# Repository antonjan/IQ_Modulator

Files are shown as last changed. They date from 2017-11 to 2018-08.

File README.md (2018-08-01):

# IQ_Modulator for Cubesat Transmitter.
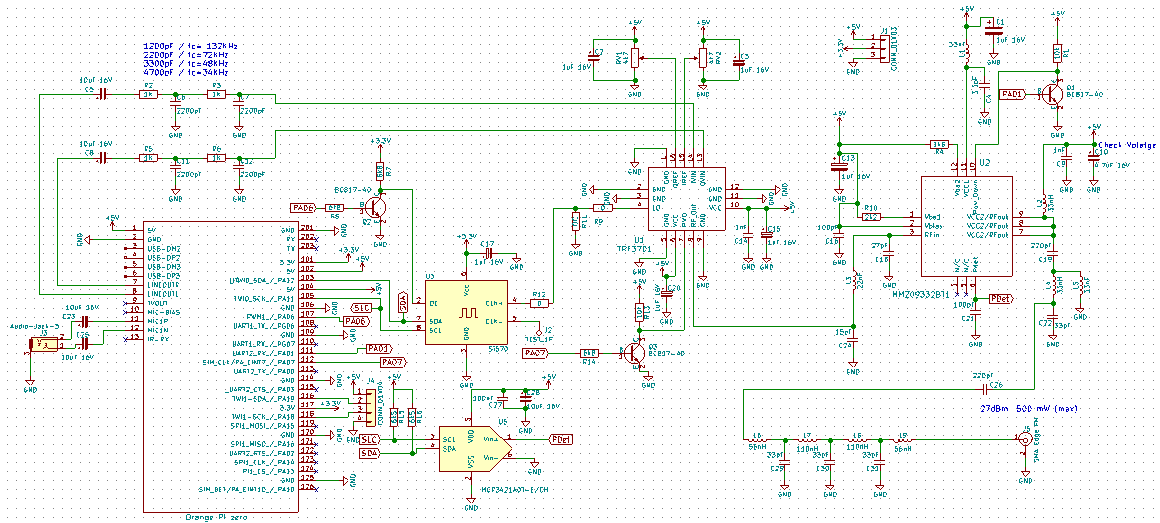
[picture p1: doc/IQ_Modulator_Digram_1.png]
<br>
IQ Modulator for 2M generating IQ stream via Audio PCM codec as modelation and using I2C to controle the RF local oselator for the RF mixer. The modulated RF signal is the Amplified to about +27dbm. (estimated 500mW)<br>
I2C Control for LO Local Osxelator with IQ moualtor RF amp and SAW and Ceremic output filters to antenna.<br>
<b><This is not complete yet still designing ></b>
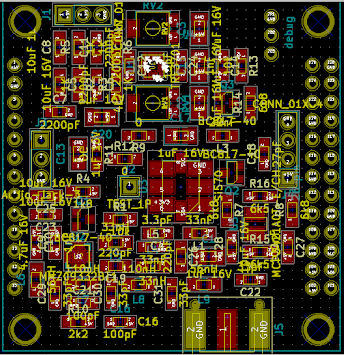
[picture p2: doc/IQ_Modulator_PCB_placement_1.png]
<br>
3d View<br>
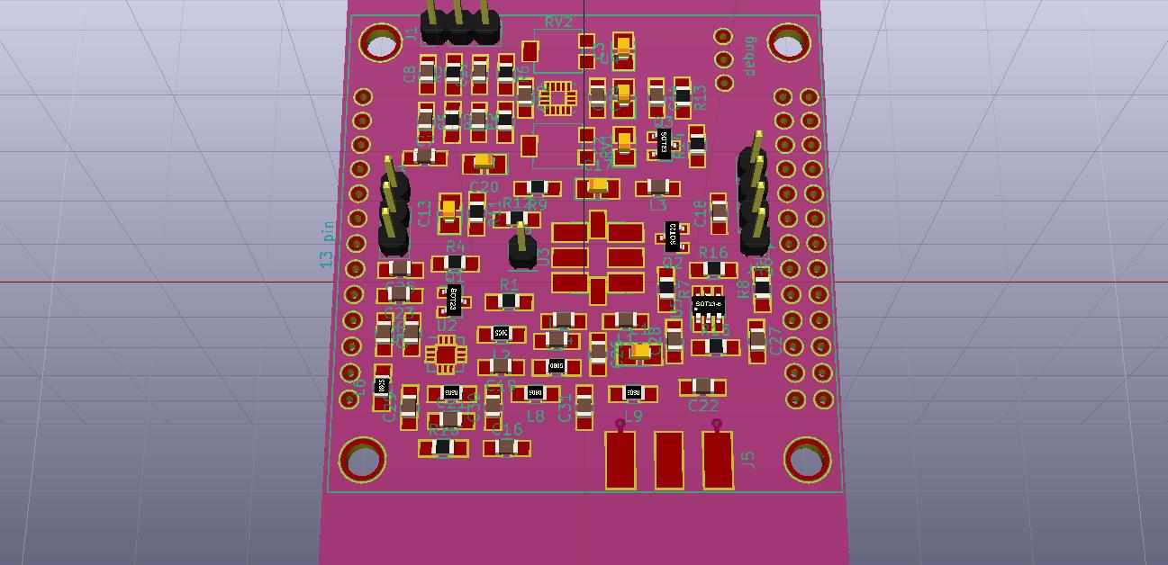
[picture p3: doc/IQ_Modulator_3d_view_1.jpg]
<br>
#Component list
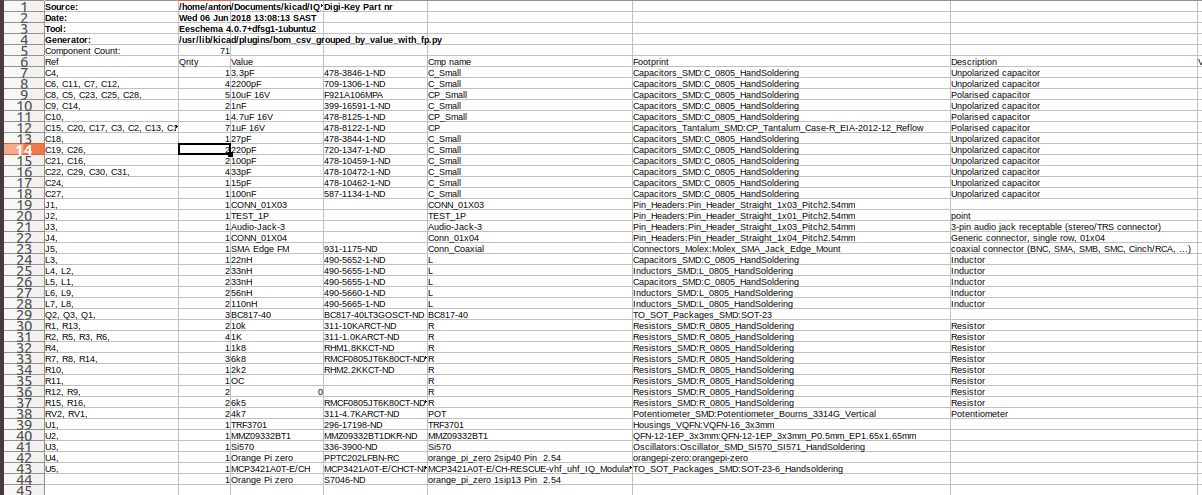
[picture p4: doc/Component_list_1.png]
<br>  
# OBC and SDR  
I am considering using Orange Pi rather than Raspberry as it has build in Audio in and out with a smaller footprint<br>
An another advantage of the Orange Pi is the additional USB ports witch I want to enable for the RTL dongle to be used as receiver.<br>
The software concept was tested using gnuradio for transponder with a hackrf for TX and a rtl sdr dongle for RX.<br>
I am still working on the telemetry witch works on its own but I need to combine it with Gnuraio transponder.<br>
I have to telemetry modes at the moment CW send Calsign and cubesat name and settings. APRS 1200 FSK sending the status of transponder<br>
# Power
Total power usage of board still needs to be calculated but my estimation with full power is 2w including Orange pi.<br>
Power usage in sleep mode possibly 500mw<br>
The PCB design was done in Kicad<br>
<br>
# Project Status.
This project is not compleet yet. (Almost done 12/06/2018)  
My plan is to have it working by 15 July 2018.
The board V3 has the wrong pin configuration for U2 trf3701
I am now working on V4 ans need to get it working by 9 August 2018 for the BACAR6 baloon project.
# Todo
1) Real time clock (done) I had to remove the Real time clock as there is not enuf space on the PCB<br>
2) I2C pull up resistors (done)<br>
3) Maybe different 70cm filter. (2m filter was changed to discrete components pi 5 stage 40db down. The 70cm filter was removed as there was now space on the PCB)<br>
4) CS for ic's<br>
5) Temprature and Tx power measurementA/D. (The A/D was added using MCP3421A0T-E/CH and will read the power output of the MMZ09332BT1 30db power amp that should give us about +27dbm. This A/D reading can then be used to adjust the ALC level in the IQ stream)<br>
6) Battery and solar Voltage Monitoring (A/D) (I had to remove this as there was no space on the PCB Board)<br>
7) I forgot to add a 4k7 resistor to base of Q1. Fixed and is now added.
8) Board placement redone thats why I have vertion 3 as I could not root all routes.  
# Constranes 
1) Small Board to fit all components.
2) My Pick and Place machien can not place components smaller that 0805.  
# Software
The software for this Board will be in the following repository
https://github.com/antonjan/Balloon-Transponder

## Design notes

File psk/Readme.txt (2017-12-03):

Deails here http://www.radiotecnia.es/raspberry-pi-based-psk31-transmitter/

The service must be run with root permissions. Help is shown with this command:

pi@raspberrypi ~/psk31 $ ./psk31 --help
Options:
 --amplitude=<n> Signal amplitude (0 .. 1]
 --clock-div=<n> Fractional divisor for carrier [4096 .. 16773120]
 Note: frequency = 500 MHz / (clock-div / 4096)
 --frequency=<f> Carrier frequency, in MHz [0.125 .. 500]
 Note: this is overridden by clock-div
 --help Show this help
 --mash=<n> Set number of MASH stages [0 .. 3]
 --pcm Use PCM clock instead of PWM clock for signal generation
 --rc=<f> Set signal filter RC value (s)
 --timeout=<n> Number of zeros before switching off. 0 for infinite.

Amplitude should be the highest. “mash” parameter should be set to ‘1’. A ‘0’ value disables fractional pll values above 25 MHz. “rc” time constant should be that of the filter we have built. If we run the program with these parameters, an unmodulated carrier is sent:

    sudo ./psk31 --mash=1 --rc=0.0047 --timeout=20 --frequency=7.042

No root permissions are needed for sending text. We can dump the content on the transmission buffer through /dev/psk31.data device as shown:

    echo "CQ CQ" > /dev/psk31.data

    cat fichero.txt > /dev/psk31.data

In this way:

    cat > /dev/psk31.data

we enter an interactive mode. We can write in the console and <Enter> sends the line to the buffer.

We can run this command to know the state of the service:

    nc -U /dev/psk31.stat

Which returns:

    amplitude 0.900000
    rc 0.004700
    clock_div 290826
    clock_mash 1
    clock_freq 7.042011
    timeout 20
    pending_char 53

To stop the service:

    sudo killall psk31

The actual divider value is not the “clock_div” number. The pll has a 500 MHz reference which is divided by a number with integer and fractional parts each represented with 12 bits. That is to say, it can divide fractions 2^12 or 4096 times smaller than one. In this case, 290826 means 500 is divided by 71 + 10/4096 (as 71·4096=290816). We have launched the service for 7.042 MHz which is obtained as 500 · 4096 / 290826 = 7.042.

This also means the resolution (the frequency step) is not fixed, but dependent on the starting frequency. Being ‘N’ an integer number between 2^13 and 2^23 that is 8.192 and 8.388.608, by means of this equation:

F = 500e6/(N/4096) [Hz]

we get frequencies between 244 kHz and 250 MHz. The rest of dividing N by 4096 (2¹²) is the fractional part.

The resolution is:

f1-f2 = 500e6/(N/4096) – 500e6/((N+1)/4096))

After some algebra:

f1 – f2 = f1² / (500e6*4096) [Hz]

Which means the resolution step is proportional to the square of the frequency.

For example, in 145 MHz  10 kHz.
In 50 MHz the step is 1,2 kHz.
In 28 MHz the step is 382 Hz.
In 7 MHz the step is 24 Hz.

This video shows the first trials of the prototype, without amplification, transmitting a short text across the room:

Conclusions and future prospects

My signal in 20 and 40 meters bands was heard 5 km away. This circuit can be improved regarding the schematic, pcb design and component election, but its goal was proving the feasibility of the idea. It is not supposed to be a convinient way to make QSOs because, among other things, a separate receiver and decoder would be needed. But it could be useful as an autonomous beacon for telemetry or propagation study. Moreover, the sigma-delta and the baseband coupling are tools which can be utilized in different projects.

The circuit could be improved in the following ways: pin 16 (gpio 23) is set at high level when the service is running. It could be used for biasing the base of 2N2222 transistor and prevent it from drawing current when unnecessary. The oscillator has a square waveshape and a dedicate filter for each band should be used. Likewise, SA602 differential output would be better coupled by means of a transformer in order to reduce distorsion and duplicate power. The same circuit can be used with the programs indicated above for transmitting other modulations, save for rpitx which makes use of pin 12 (gpio 18) for the PLL output instead of pin 7 (gpio 4); the connections should be made interchangeable.

By EA4GMZ • Electrónica y equipos, Otros •

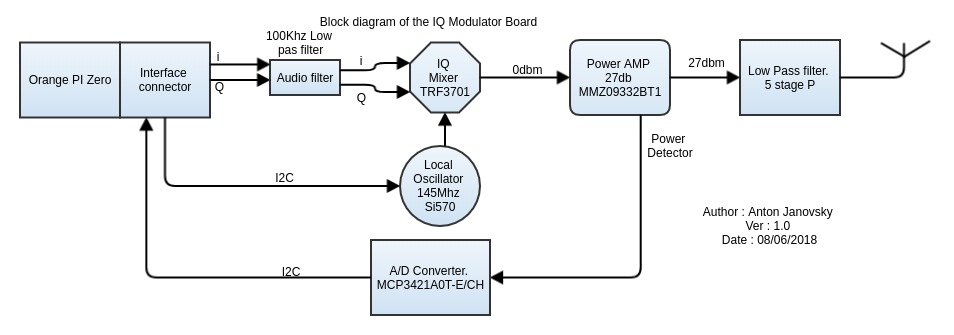
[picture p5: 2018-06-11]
doc/IQ_Modulator_Block_Diagram_v1.jpg

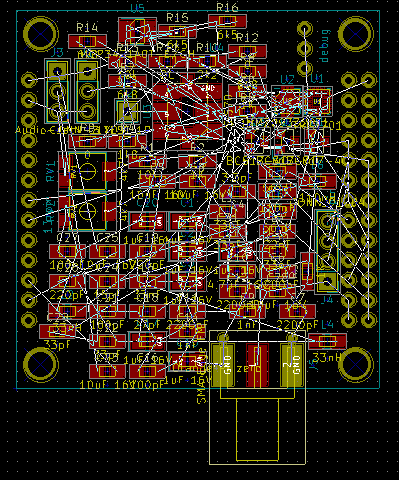
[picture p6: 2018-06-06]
doc/IQ_Modulator_PCB_1.png

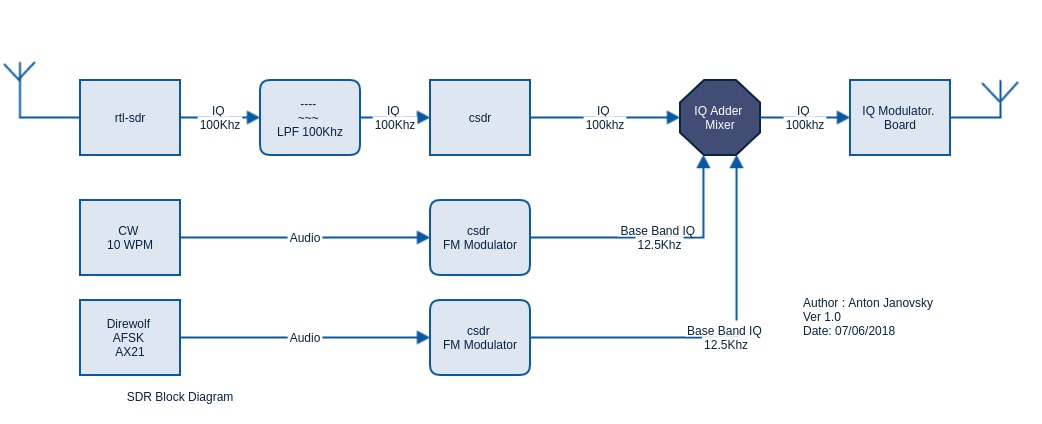
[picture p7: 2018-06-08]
doc/Block_Diagram_v1.jpg

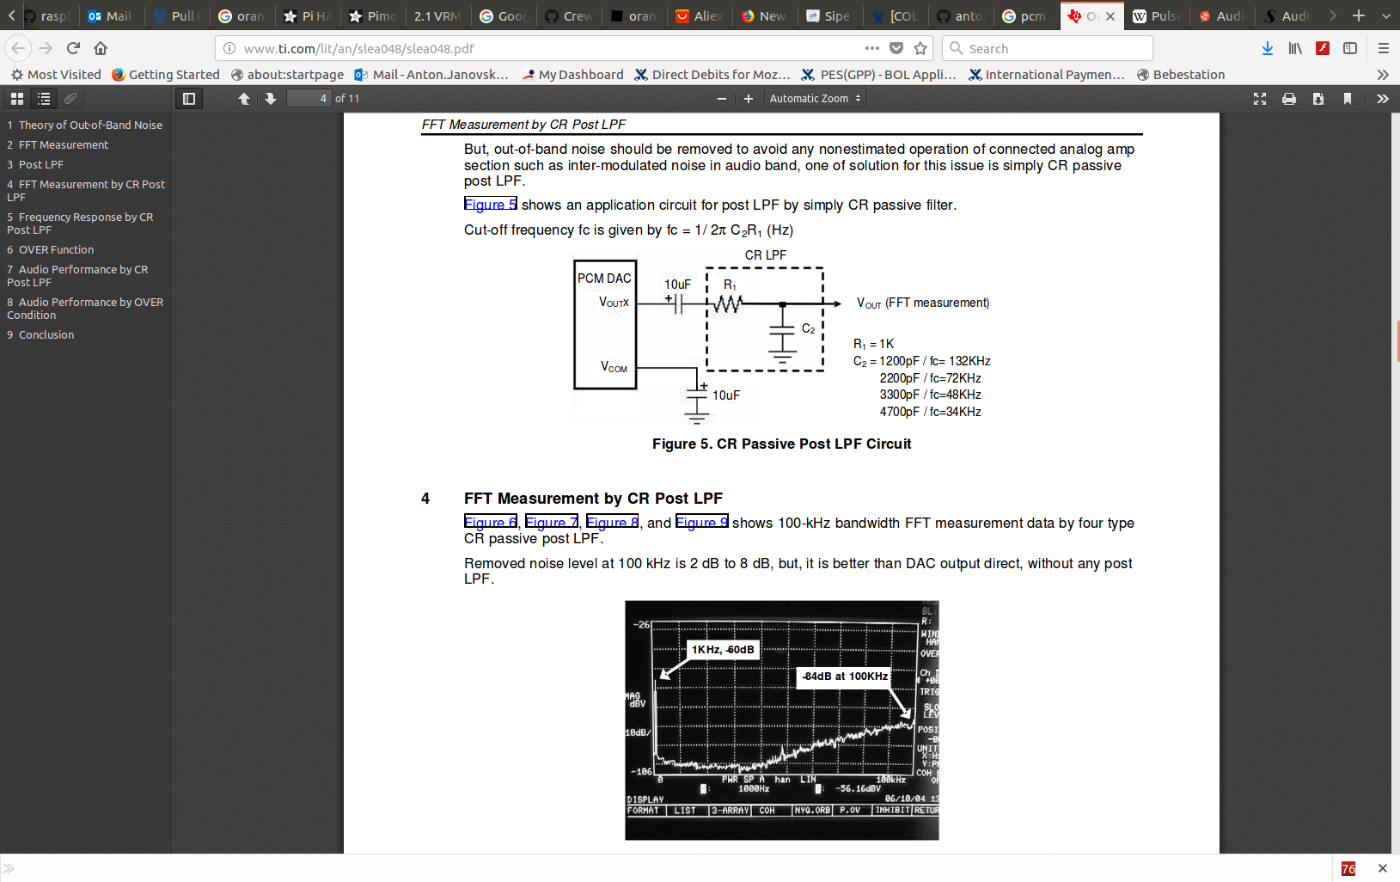
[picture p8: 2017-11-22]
Audio_output_Filter.png

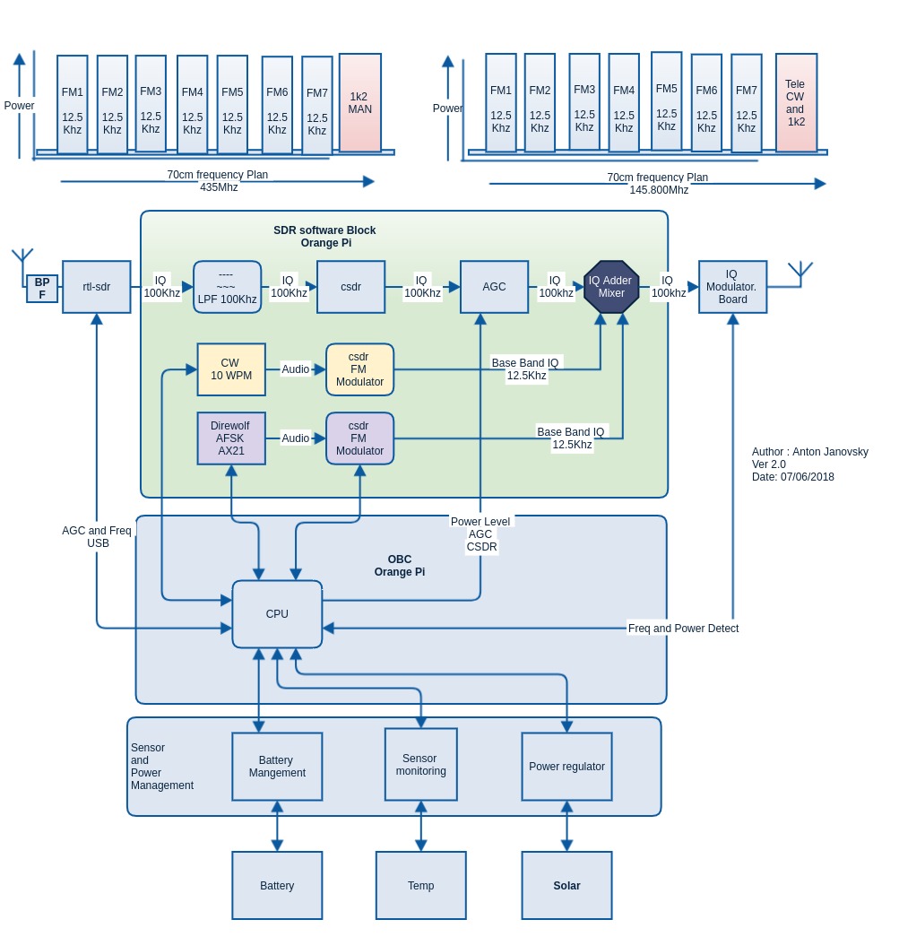
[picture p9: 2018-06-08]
doc/Block_Diagram_v2.jpg

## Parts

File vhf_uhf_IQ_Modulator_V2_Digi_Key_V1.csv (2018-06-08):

# | Quantity | Part Number | Manufacturer Part Number | Description | Customer Reference | Backorder | Unit Price | Extended Price
1 | 100 | 478-3846-1-ND | 08052U3R3DAT2A | CAP CER 3.3PF 200V C0G/NP0 0805 | 3.3PF | 0 | 180,540 | R 180,54
2 | 100 | 399-16591-1-ND | C0805C102J5HACAUTO | CAP CER 0805 1NF 50V ULTRA STABL | 1NF | 0 | 81,130 | R 81,13
3 | 100 | 478-8125-1-ND | F921A475MPA | CAP TANT 4.7UF 10V 20% 0805 | 4.7UF 16V | 0 | 185,550 | R 185,55
4 | 100 | 478-3844-1-ND | 08052U270JAT2A | CAP CER 27PF 200V C0G/NP0 0805 | 27PF | 0 | 166,270 | R 166,27
5 | 100 | 478-10472-1-ND | 08052U330JAT2A | CAP CER 33PF 200V NP0 0805 | 33PF | 0 | 188,930 | R 188,93
6 | 100 | 587-1134-1-ND | LMK212SD104KG-T | CAP CER 0.1UF 10V 0805 | 100NF | 0 | 210,840 | R 210,84
7 | 50 | 490-5652-1-ND | LQW2BAS22NJ00L | FIXED IND 22NH 500MA 220 MOHM | 22NH | 0 | 198,820 | R 99,41
8 | 50 | 490-5655-1-ND | LQW2BAS33NJ00L | FIXED IND 33NH 500MA 270 MOHM | 33NH | 0 | 265,400 | R 132,70
9 | 50 | 490-5660-1-ND | LQW2BAS56NJ00L | FIXED IND 56NH 500MA 340 MOHM | 56NH | 0 | 198,820 | R 99,41
10 | 50 | 490-5665-1-ND | LQW2BASR11J00L | FIXED IND 110NH 400MA 480 MOHM | 110NH | 0 | 198,820 | R 99,41
11 | 4 | 296-17198-ND | TRF3701IRHC | IC QUADRATURE MODULATOR 16-VQFN | TRF3701 | 0 | 20,896,000 | R 835,84
12 | 4 | MMZ09332BT1DKR-ND | MMZ09332BT1 | IC AMP HBT INGAP | MMZ09332BT1 | 0 | 12,992,000 | R 519,68
13 | 4 | 336-3900-ND | 570MAC000118DG | OSC XO 100KHZ-250MHZ LVPECL SMD | SI570 | 0 | 14,398,000 | R 575,92
14 | 4 | MCP3421A0T-E/CHCT-ND | MCP3421A0T-E/CH | IC ADC 18BIT 3.75SPS 1CH SOT23-6 | MCP3421A0T-E/CH | 0 | 3,080,000 | R 123,20
15 | 100 | 311-3619-1-ND | CC0805JRX7R9BB222 | CAP CER 2200PF 50V X7R 0805 | 2200PF | 0 | 40,560 | R 40,56
16 | 20 | 490-6104-1-ND | GR442QR73D221KW01L | CAP CER 220PF 2KV X7R 1808 | 220PF | 0 | 472,000 | R 94,40
17 | 100 | 1276-2585-1-ND | CL21C150JB61PNC | CAP CER 15PF 50V C0G/NP0 0805 | 15PF | 0 | 67,610 | R 67,61

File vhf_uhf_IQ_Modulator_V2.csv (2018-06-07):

Source: | /home/anton/Documents/kicad/IQ_Modulator/vhf_uhf_IQ_Modulator_V2.sch |  | Digi-Key Part nr
Date: | Wed 06 Jun 2018 13:08:13 SAST
Tool: | Eeschema 4.0.7+dfsg1-1ubuntu2
Generator: | /usr/lib/kicad/plugins/bom_csv_grouped_by_value_with_fp.py
Component Count: | 71
Ref | Qnty | Value |  | Cmp name | Footprint | Description | Vendor
C4, | 1 | 3.3pF | 478-3846-1-ND | C_Small | Capacitors_SMD:C_0805_HandSoldering | Unpolarized capacitor
C6, C11, C7, C12, | 4 | 2200pF | 709-1306-1-ND | C_Small | Capacitors_SMD:C_0805_HandSoldering | Unpolarized capacitor
C8, C5, C23, C25, C28, | 5 | 10uF 16V | 478-11412-1-ND | CP_Small | Capacitors_SMD:C_0805_HandSoldering | Polarised capacitor
C9, C14, | 2 | 1nF | 399-16591-1-ND | C_Small | Capacitors_SMD:C_0805_HandSoldering | Unpolarized capacitor
C10, | 1 | 4.7uF 16V | 478-8125-1-ND | CP_Small | Capacitors_SMD:C_0805_HandSoldering | Polarised capacitor
C15, C20, C17, C3, C2, C13, C1, | 7 | 1uF 16V | 478-8122-1-ND | CP | Capacitors_Tantalum_SMD:CP_Tantalum_Case-R_EIA-2012-12_Reflow | Polarised capacitor
C18, | 1 | 27pF | 478-3844-1-ND | C_Small | Capacitors_SMD:C_0805_HandSoldering | Unpolarized capacitor
C19, C26, | 2 | 220pF | 720-1347-1-ND | C_Small | Capacitors_SMD:C_0805_HandSoldering | Unpolarized capacitor
C21, C16, | 2 | 100pF | 478-10459-1-ND | C_Small | Capacitors_SMD:C_0805_HandSoldering | Unpolarized capacitor
C22, C29, C30, C31, | 4 | 33pF | 478-10472-1-ND | C_Small | Capacitors_SMD:C_0805_HandSoldering | Unpolarized capacitor
C24, | 1 | 15pF | 478-10462-1-ND | C_Small | Capacitors_SMD:C_0805_HandSoldering | Unpolarized capacitor
C27, | 1 | 100nF | 587-1134-1-ND | C_Small | Capacitors_SMD:C_0805_HandSoldering | Unpolarized capacitor
J1, | 1 | CONN_01X03 |  | CONN_01X03 | Pin_Headers:Pin_Header_Straight_1x03_Pitch2.54mm
J2, | 1 | TEST_1P |  | TEST_1P | Pin_Headers:Pin_Header_Straight_1x01_Pitch2.54mm | point
J3, | 1 | Audio-Jack-3 |  | Audio-Jack-3 | Pin_Headers:Pin_Header_Straight_1x03_Pitch2.54mm | 3-pin audio jack receptable (stereo/TRS connector)
J4, | 1 | CONN_01X04 |  | Conn_01x04 | Pin_Headers:Pin_Header_Straight_1x04_Pitch2.54mm | Generic connector, single row, 01x04
J5, | 1 | SMA Edge FM | 931-1175-ND | Conn_Coaxial | Connectors_Molex:Molex_SMA_Jack_Edge_Mount | coaxial connector (BNC, SMA, SMB, SMC, Cinch/RCA, ...)
L3, | 1 | 22nH | 490-5652-1-ND | L | Capacitors_SMD:C_0805_HandSoldering | Inductor
L4, L2, | 2 | 33nH | 490-5655-1-ND | L | Inductors_SMD:L_0805_HandSoldering | Inductor
L5, L1, | 2 | 33nH | 490-5655-1-ND | L | Capacitors_SMD:C_0805_HandSoldering | Inductor
L6, L9, | 2 | 56nH | 490-5660-1-ND | L | Inductors_SMD:L_0805_HandSoldering | Inductor
L7, L8, | 2 | 110nH | 490-5665-1-ND | L | Inductors_SMD:L_0805_HandSoldering | Inductor
Q2, Q3, Q1, | 3 | BC817-40 | BC817-40LT3GOSCT-ND | BC817-40 | TO_SOT_Packages_SMD:SOT-23
R1, R13, | 2 | 10k | 311-10KARCT-ND | R | Resistors_SMD:R_0805_HandSoldering | Resistor
R2, R5, R3, R6, | 4 | 1K | 311-1.0KARCT-ND | R | Resistors_SMD:R_0805_HandSoldering | Resistor
R4, | 1 | 1k8 | RHM1.8KKCT-ND | R | Resistors_SMD:R_0805_HandSoldering | Resistor
R7, R8, R14, | 3 | 6k8 | RMCF0805JT6K80CT-ND | R | Resistors_SMD:R_0805_HandSoldering | Resistor
R10, | 1 | 2k2 | RHM2.2KKCT-ND | R | Resistors_SMD:R_0805_HandSoldering | Resistor
R11, | 0 | OC |  | R | Resistors_SMD:R_0805_HandSoldering | Resistor
R12, R9, | 2 | 0 | 541-0.0ACT-ND | R | Resistors_SMD:R_0805_HandSoldering | Resistor
R15, R16, | 2 | 6k5 | RMCF0805JT6K80CT-ND | R | Resistors_SMD:R_0805_HandSoldering | Resistor
RV2, RV1, | 2 | 4k7 | 311-4.7KARCT-ND | POT | Potentiometer_SMD:Potentiometer_Bourns_3314G_Vertical | Potentiometer
U1, | 1 | TRF3701 | 296-17198-ND | TRF3701 | Housings_VQFN:VQFN-16_3x3mm
U2, | 1 | MMZ09332BT1 | MMZ09332BT1DKR-ND | MMZ09332BT1 | QFN-12-1EP_3x3mm:QFN-12-1EP_3x3mm_P0.5mm_EP1.65x1.65mm
U3, | 1 | Si570 | 336-3900-ND | Si570 | Oscillators:Oscillator_SMD_SI570_SI571_HandSoldering
U4, | 1 | Orange Pi zero | PPTC202LFBN-RC | orange_pi_zero 2sip40 Pin 2.54 | orangepi-zero:orangepi-zero
U5, | 1 | MCP3421A0T-E/CH | MCP3421A0T-E/CHCT-ND | MCP3421A0T-E/CH-RESCUE-vhf_uhf_IQ_Modulator | TO_SOT_Packages_SMD:SOT-23-6_Handsoldering
 | 1 | Orange Pi zero | S7046-ND | orange_pi_zero 1sip13 Pin 2.54

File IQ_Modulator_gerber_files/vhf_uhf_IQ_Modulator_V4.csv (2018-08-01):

Id | Designator | Package | Quantity | Designation | Supplier and ref
1 | C1,C2,C3,C13,C15,C17,C20 | CP_Tantalum_Case-R_EIA-2012-12_Reflow | 7 | 1uF 16V
2 | C4 | C_0805_HandSoldering | 1 | 3.3pF
3 | C5,C8,C23,C25,C28 | C_0805_HandSoldering | 5 | 10uF 16V
4 | C6,C7,C11,C12 | C_0805_HandSoldering | 4 | 2200pF
5 | C9,C14 | C_0805_HandSoldering | 2 | 1nF
6 | C10 | C_0805_HandSoldering | 1 | 4.7uF 16V
7 | C16,C21 | C_0805_HandSoldering | 2 | 100pF
8 | C18 | C_0805_HandSoldering | 1 | 27pF
9 | C19,C26 | C_0805_HandSoldering | 2 | 220pF
10 | C22,C29,C30,C31 | C_0805_HandSoldering | 4 | 33pF
11 | C24 | C_0805_HandSoldering | 1 | 15pF
12 | C27 | C_0805_HandSoldering | 1 | 100nF
13 | J1 | Pin_Header_Straight_1x03_Pitch2.54mm | 1 | CONN_01X03
14 | J2 | Pin_Header_Straight_1x01_Pitch2.54mm | 1 | TEST_1P
15 | J3 | Pin_Header_Straight_1x03_Pitch2.54mm | 1 | Audio-Jack-3
16 | J4 | Pin_Header_Straight_1x04_Pitch2.54mm | 1 | CONN_01X04
17 | J5 | Molex_SMA_Jack_Edge_Mount | 1 | SMA Edge FM
18 | L1,L5 | C_0805_HandSoldering | 2 | 33nF
19 | L2,L4 | L_0805_HandSoldering | 2 | 33nH
20 | L3 | C_0805_HandSoldering | 1 | 22nF
21 | L6,L9 | L_0805_HandSoldering | 2 | 56nH
22 | L7,L8 | L_0805_HandSoldering | 2 | 110nH
23 | Q1,Q2,Q3 | SOT-23 | 3 | BC817-40
24 | R1,R13 | R_0805_HandSoldering | 2 | 10k
25 | R2,R3,R5,R6 | R_0805_HandSoldering | 4 | 1K
26 | R4 | R_0805_HandSoldering | 1 | 1k8
27 | R7,R8,R14 | R_0805_HandSoldering | 3 | 6k8
28 | R9,R12 | R_0805_HandSoldering | 2 | 0
29 | R10 | R_0805_HandSoldering | 1 | 2k2
30 | R11 | R_0805_HandSoldering | 1 | OC
31 | R15,R16 | R_0805_HandSoldering | 2 | 6k5
32 | RV1,RV2 | Potentiometer_Bourns_3314G_Vertical | 2 | 4k7
33 | U2 | QFN-12-1EP_3x3mm_P0.5mm_EP1.65x1.65mm | 1 | MMZ09332BT1
34 | U3 | Oscillator_SMD_SI570_SI571_HandSoldering | 1 | Si570
35 | U4 | orangepi-zero | 1 | Orange Pi zero
36 | U5 | SOT-23-6_Handsoldering | 1 | MCP3421A0T-E/CH
37 | R17 | R_0805_HandSoldering | 1 | 4k7
38 | U1 | VQFN-16_3x3mm_trf3701_new | 1 | TRF3701

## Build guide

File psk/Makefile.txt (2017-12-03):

.PHONY: all
all: psk31 varicode
	@echo Done

psk31: psk31.c
	@echo '   CC   $^'
	@gcc -O6 -Wall -o $@ $^ -lm

varicode: varicode.c
	@echo '   CC   $^'
	@gcc -o $@ $^

.PHONY: clean
clean:
	@rm -f psk31 varicode

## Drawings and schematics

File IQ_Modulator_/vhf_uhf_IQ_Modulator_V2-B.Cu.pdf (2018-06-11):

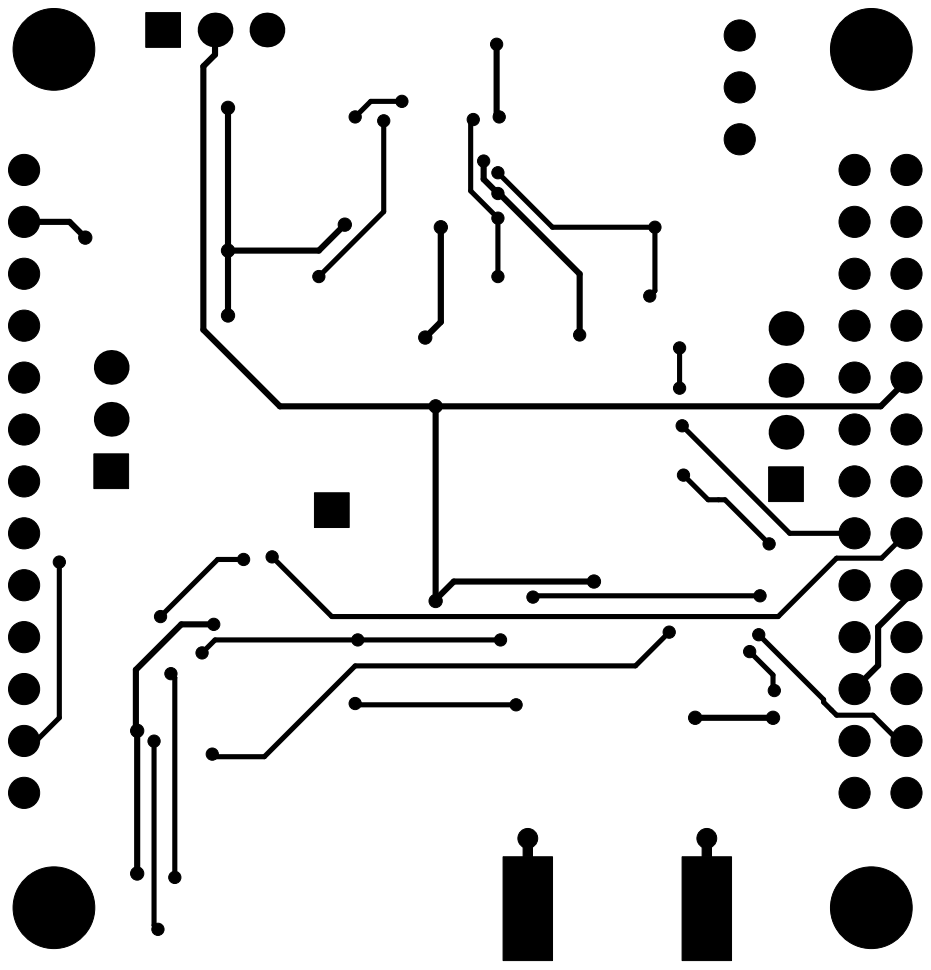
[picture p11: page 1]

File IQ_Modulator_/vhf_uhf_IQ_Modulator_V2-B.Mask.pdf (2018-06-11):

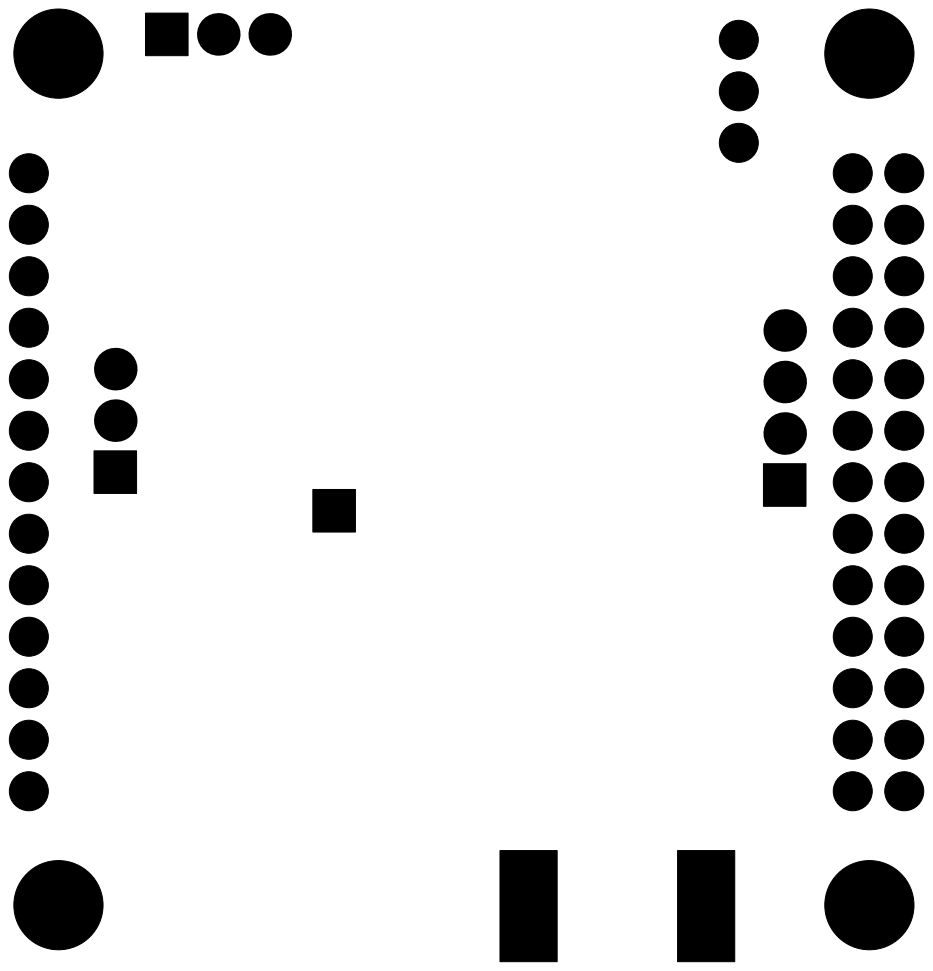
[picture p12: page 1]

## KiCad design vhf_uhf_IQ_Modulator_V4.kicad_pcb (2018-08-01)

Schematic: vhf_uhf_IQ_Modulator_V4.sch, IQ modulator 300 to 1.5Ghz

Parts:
C1, C2, C3, C13, C15, C17, C20: 1uF 16V; CP_Tantalum_Case-R_EIA-2012-12_Reflow
C4: 3.3pF; C_0805_HandSoldering
C5, C8, C23, C25, C28: 10uF 16V; C_0805_HandSoldering
C6, C7, C11, C12: 2200pF; C_0805_HandSoldering
C9, C14: 1nF; C_0805_HandSoldering
C10: 4.7uF 16V; C_0805_HandSoldering
C16, C21: 100pF; C_0805_HandSoldering
C18: 27pF; C_0805_HandSoldering
C19, C26: 220pF; C_0805_HandSoldering
C22, C29, C30, C31: 33pF; C_0805_HandSoldering
C24: 15pF; C_0805_HandSoldering
C27: 100nF; C_0805_HandSoldering
J1: CONN_01X03; Pin_Header_Straight_1x03_Pitch2.54mm
J2: TEST_1P; Pin_Header_Straight_1x01_Pitch2.54mm
J3: Audio-Jack-3; Pin_Header_Straight_1x03_Pitch2.54mm
J4: CONN_01X04; Pin_Header_Straight_1x04_Pitch2.54mm
J5: SMA Edge FM; Molex_SMA_Jack_Edge_Mount
L1, L5: 33nF; C_0805_HandSoldering
L2, L4: 33nH; L_0805_HandSoldering
L3: 22nF; C_0805_HandSoldering
L6, L9: 56nH; L_0805_HandSoldering
L7, L8: 110nH; L_0805_HandSoldering
Q1, Q2, Q3: BC817-40; SOT-23
R1, R13: 10k; R_0805_HandSoldering
R2, R3, R5, R6: 1K; R_0805_HandSoldering
R4: 1k8; R_0805_HandSoldering
R7, R8, R14: 6k8; R_0805_HandSoldering
R9, R12: 0; R_0805_HandSoldering
R10: 2k2; R_0805_HandSoldering
R11: OC; R_0805_HandSoldering
R15, R16: 6k5; R_0805_HandSoldering
R17: 4k7; R_0805_HandSoldering
RV1, RV2: 4k7; Potentiometer_Bourns_3314G_Vertical
U1: TRF3701; VQFN-16_3x3mm_trf3701_new
U2: MMZ09332BT1; QFN-12-1EP_3x3mm_P0.5mm_EP1.65x1.65mm
U3: Si570; Oscillator_SMD_SI570_SI571_HandSoldering
U4: Orange Pi zero; orangepi-zero
U5: MCP3421A0T-E/CH; SOT-23-6_Handsoldering

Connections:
+3V3: C17.1, J1.2, R7.2, U3.6, U4.101, U4.117
+5V: C1.1, C2.1, C3.1, C9.2, C10.1, C13.1, C14.2, C15.1, C16.2, C20.1, C27.2, C28.1, J1.1, J4.1, L1.1, L2.1, R1.2, R4.2, R10.2, R13.1, R15.1, R16.1, RV1.1, RV2.1, U1.6, U1.10, U2.2, U4.1, U4.102, U4.104, U5.5
GND: C1.2, C2.2, C3.2, C4.1, C6.2, C7.2, C9.1, C10.2, C11.2, C12.2, C13.2, C14.1, C15.2, C16.1, C17.2, C18.1, C20.2, C21.1, C22.1, C24.1, C27.1, C28.2, C29.1, C30.1, C31.1, J1.3, J3.3, J4.4, J5.2, L5.2, Q1.2 (E), Q2.2 (E), Q3.2 (E), R11.1, RV1.3, RV2.3, U1.1, U1.2, U1.3, U1.5, U1.9, U1.11, U1.12, U1.17, U2.13, U3.3, U4.2, U4.106, U4.109, U4.114, U4.120, U4.125, U4.201, U5.2, U5.6
unnamed: C4.2, L1.2, U2.11
unnamed: C5.1, U4.8
unnamed: C5.2, R2.2
unnamed: C6.1, R2.1, R3.2
unnamed: C7.1, R3.1, U1.14
unnamed: C8.1, U4.7
unnamed: C8.2, R5.2
unnamed: C11.1, R5.1, R6.2
unnamed: C12.1, R6.1, U1.13
unnamed: C18.2, L3.1, U2.3
unnamed: C19.1, L4.1, L5.1
unnamed: C19.2, L2.2, U2.7, U2.8, U2.9
unnamed: C22.2, C26.2, L4.2
unnamed: C23.1, J3.2
unnamed: C23.2, U4.11
unnamed: C24.2, L3.2, U1.8
unnamed: C25.1, J3.1
unnamed: C25.2, U4.12
unnamed: C26.1, L6.2
unnamed: C29.2, L6.1, L7.2
unnamed: C30.2, L7.1, L8.2
unnamed: C31.2, L8.1, L9.2
unnamed: J2.1, U3.5
unnamed: J4.2, U4.116
unnamed: J4.3, U4.118
unnamed: J5.1, L9.1
unnamed: Q1.1 (B), R17.1
unnamed: Q1.3 (C), R1.1, U2.10
unnamed: Q2.1 (B), R8.2
unnamed: Q2.3 (C), R7.1, U3.2
unnamed: Q3.1 (B), R14.2
unnamed: Q3.3 (C), R13.2, U1.7
unnamed: R4.1, U2.12
unnamed: R9.1, U1.4
unnamed: R10.1, U2.1
unnamed: R9.2, R11.2, R12.1
unnamed: R12.2, U3.4
unnamed: RV1.2, U1.15
unnamed: RV2.2, U1.16
PA01: R17.2, U4.111
PA06: R8.1, U4.107
PA07: R14.1, U4.112
PDet: C21.2, U2.6, U5.1
SDA: R16.2, U3.7, U4.103, U5.4
SLC: R15.2, U3.8, U4.105, U5.3

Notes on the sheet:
Check Volatge
1200pF / fc= 132KHz 2200pF / fc=72KHz 3300pF / fc=48KHz 4700pF / fc=34KHz
27dBm 500 mW (max)

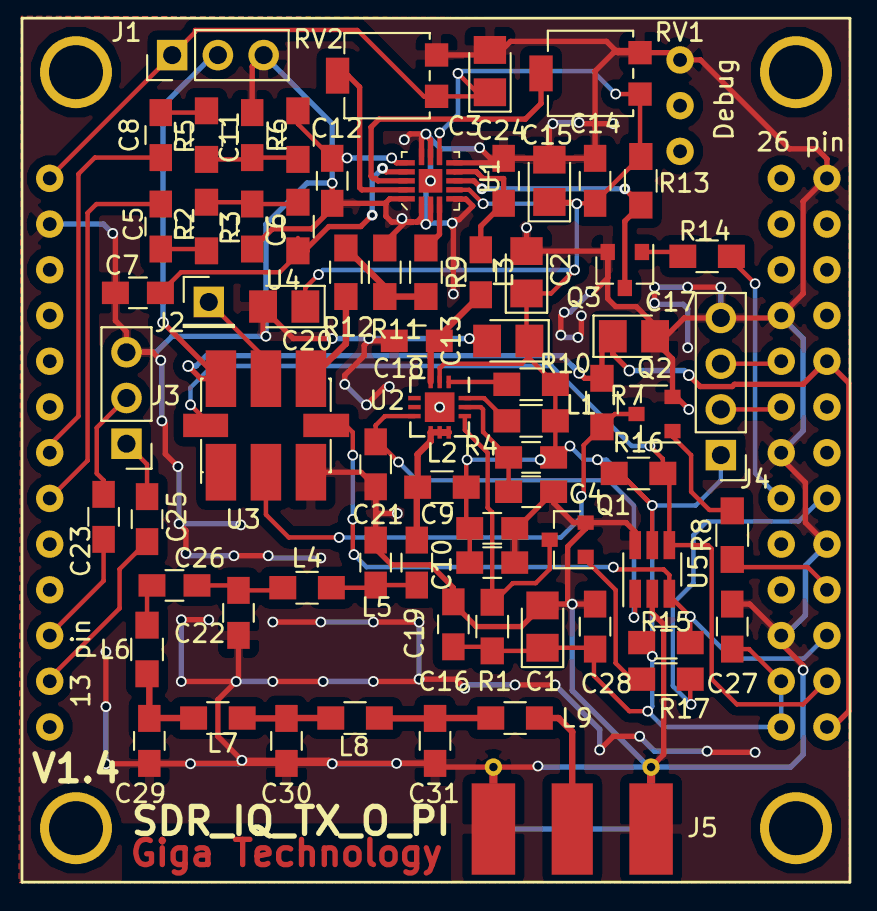
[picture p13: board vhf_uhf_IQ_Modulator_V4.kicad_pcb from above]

Board: 2 copper layers, 72 parts (0 on the bottom side), 48 nets.

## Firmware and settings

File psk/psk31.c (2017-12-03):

/*
 * This file is part of RPIO.
 *
 * Copyright
 *
 *     Copyright (C) 2013 Chris Hager <chris@linuxuser.at>
 *
 * License
 *
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
 * Documentation
 *
 *     http://pythonhosted.org/RPIO
 *
 * Based on the excellent ServoBlaster by Richard Hirst.
 *
 * Documentation
 * =============
 *
 * A server is controlled via the pulse-width within a fixed period (the
 * period is defined by the servo-maker; look it up in the datasheet).
 *
 *      |<--- Period Width (20ms) ------>|
 *
 *      +--------+                       +--------+
 *      |        |                       |        |
 * -----+        +-----------------------+        +------
 *
 *   -->|        |<-- Pulse Width (1..2ms)
 *
 *
 * This documentation is work in progress. Look here for more information:
 * - https://github.com/metachris/raspberrypi-pwm
 * - https://github.com/richardghirst/PiBits/blob/master/ServoBlaster
 */
#define _GNU_SOURCE
#include <stdio.h>
#include <stdlib.h>
#include <unistd.h>
#include <string.h>
#include <errno.h>
#include <stdarg.h>
#include <stdint.h>
#include <signal.h>
#include <time.h>
#include <sys/time.h>
#include <sys/types.h>
#include <sys/socket.h>
#include <sys/un.h>
#include <sys/stat.h>
#include <fcntl.h>
#include <sys/mman.h>
#include <math.h>
#include <unistd.h>
#include <getopt.h>

#define ARRAY_SIZE(a) (sizeof(a) / sizeof(a[0]))
#define out32(a,v) (*(volatile uint32_t *)(a) = (v))
#define in32(a) (*(volatile uint32_t *)(a))

#if 0
static uint8_t gpio_list[] = {
    4,    // P1-7
    17,    // P1-11
    18,    // P1-12
    21,    // P1-13
    22,    // P1-15
    23,    // P1-16
    24,    // P1-18
    25,    // P1-22
};
#endif
#define GPIO_FREQ_NUM 4
#define GPIO_POS_NUM 17
#define GPIO_NEG_NUM 18

#define DEVFILE_SEND "/dev/psk31.data"
#define DEVFILE_CTRL "/dev/psk31.ctrl"
#define DEVFILE_STAT "/dev/psk31.stat"

enum {
	SYM_L,
	SYM_H,
	SYM_LH,
	SYM_HL,

	SYM_COUNT
};

// PULSE_WIDTH_INCR_US is the pulse width increment granularity, again in microseconds.
// Setting it too low will likely cause problems as the DMA controller will use too much
//memory bandwidth. 10us is a good value, though you might be ok setting it as low as 2us.
#define PULSE_WIDTH_INCR_US  10

#define BS_US                32000
#define BS_SAMPLES           (BS_US / PULSE_WIDTH_INCR_US)
#define TS_SHIFT             4
#define TS_COUNT             (1 << TS_SHIFT)
#define TS_US                BS_US

// Various
#define NUM_SAMPLES          (BS_SAMPLES * SYM_COUNT * TS_COUNT)
#define NUM_CBS              (NUM_SAMPLES * 3)

#define PAGE_SIZE            4096
#define PAGE_SHIFT           12
#define NUM_PAGES_CBS        ((NUM_CBS * 32 + PAGE_SIZE - 1) >> PAGE_SHIFT)
#define NUM_PAGES_SAMPLES    ((2 * 4 + PAGE_SIZE - 1) >> PAGE_SHIFT)
#define NUM_PAGES            (NUM_PAGES_CBS + NUM_PAGES_SAMPLES)



// Memory Addresses
#define DMA_BASE        0x20007000
#define DMA_LEN         0x24
#define PWM_BASE        0x2020C000
#define PWM_LEN         0x28
#define CLK_BASE        0x20101000
#define CLK_LEN         0xA8
#define GPIO_BASE       0x20200000
#define GPIO_LEN        0x100
#define PCM_BASE        0x20203000
#define PCM_LEN         0x24

#define DMA_NO_WIDE_BURSTS  (1<<26)
#define DMA_WAIT_RESP   (1<<3)
#define DMA_D_DREQ      (1<<6)
#define DMA_PER_MAP(x)  ((x)<<16)
#define DMA_END         (1<<1)
#define DMA_RESET       (1<<31)
#define DMA_INT         (1<<2)

#define DMA_CS          (0x00/4)
#define DMA_CONBLK_AD   (0x04/4)
#define DMA_DEBUG       (0x20/4)

// GPIO Memory Addresses
#define GPIO_FSEL0      (0x00/4)
#define GPIO_SET0       (0x1c/4)
#define GPIO_CLR0       (0x28/4)
#define GPIO_LEV0       (0x34/4)
#define GPIO_PULLEN     (0x94/4)
#define GPIO_PULLCLK    (0x98/4)

// GPIO Modes (IN=0, OUT=1)
#define GPIO_MODE_IN    0
#define GPIO_MODE_OUT   1
#define GPIO_MODE_ALT0  4
#define GPIO_MODE_ALT1  5
#define GPIO_MODE_ALT2  6
#define GPIO_MODE_ALT3  7
#define GPIO_MODE_ALT4  3
#define GPIO_MODE_ALT5  2

// PWM Memory Addresses
#define PWM_CTL         (0x00/4)
#define PWM_DMAC        (0x08/4)
#define PWM_RNG1        (0x10/4)
#define PWM_FIFO        (0x18/4)

#define PWMCLK_CNTL     40
#define PWMCLK_DIV      41

#define PWMCTL_MODE1    (1<<1)
#define PWMCTL_PWEN1    (1<<0)
#define PWMCTL_CLRF     (1<<6)
#define PWMCTL_USEF1    (1<<5)

#define PWMDMAC_ENAB    (1<<31)
#define PWMDMAC_THRSHLD ((15<<8) | (15<<0))

#define PCM_CS_A        (0x00/4)
#define PCM_FIFO_A      (0x04/4)
#define PCM_MODE_A      (0x08/4)
#define PCM_RXC_A       (0x0c/4)
#define PCM_TXC_A       (0x10/4)
#define PCM_DREQ_A      (0x14/4)
#define PCM_INTEN_A     (0x18/4)
#define PCM_INT_STC_A   (0x1c/4)
#define PCM_GRAY        (0x20/4)

#define PCMCLK_CNTL     38
#define PCMCLK_DIV      39

#define DELAY_VIA_PWM   0
#define DELAY_VIA_PCM   1

/* General Purpose Clock */
#define CM_GP0CTL       (0x70 / 4)
#define CM_GP1CTL       (0x78 / 4)
#define CM_GP2CTL       (0x80 / 4)
#define CM_GP0DIV       (0x74 / 4)
#define CM_GP1DIV       (0x7c / 4)
#define CM_GP2DIV       (0x84 / 4)

typedef struct {
	uint32_t info;
	uint32_t src;
	uint32_t dst;
	uint32_t length;
	uint32_t stride;
	uint32_t next;
	uint32_t pad_1;
	uint32_t pad_2;
} dma_cb_t;

struct ctl {
	union {
		dma_cb_t cb[NUM_CBS];
		char cb_pages[NUM_PAGES_CBS][PAGE_SIZE];
	};
	union {
		uint32_t samples[2];
		char samples_pages[NUM_PAGES_SAMPLES][PAGE_SIZE];
	};
};

typedef struct {
	uint32_t physaddr;   /* Starting address */
	dma_cb_t *cb_last;   /* Last CB */
} bs_info_t;

typedef struct {
	bs_info_t bs[SYM_COUNT];
	uint32_t physaddr;
} ts_info_t;

ts_info_t ts_info[TS_COUNT];
int ts_last;
dma_cb_t *ts_last_cbp;
int ts_last_sym;

static const int ts_next[SYM_COUNT][2] = {
	[SYM_L] = {SYM_LH, SYM_L},
	[SYM_H] = {SYM_HL, SYM_H},
	[SYM_LH] = {SYM_HL, SYM_H},
	[SYM_HL] = {SYM_LH, SYM_L},
};

typedef struct {
    uint8_t *virtaddr;
    uint32_t physaddr;
} page_map_t;

page_map_t *page_map;
page_map_t *phys_info;

static uint8_t *virtbase;

static volatile uint32_t *pwm_reg;
static volatile uint32_t *pcm_reg;
static volatile uint32_t *clk_reg;
static volatile uint32_t *dma_reg;
static volatile uint32_t *gpio_reg;

static int delay_hw = DELAY_VIA_PWM;

static double pi;
static double option_amplitude = 0.9;
static double option_frequency = 0;
static int option_div = 0;
static int option_mash = 3;
static double option_rc = 4700.0 * 0.000001;
static int option_timeout = -1;
static double level_error_max;

typedef struct {
	int b_len;
	int b_val;
} burst_t;

static const burst_t starting_burst = {20, 0};
static const burst_t ending_burst = {20, 0x000fffff};
static const burst_t fill_burst = {1, 0};
static const burst_t idle_burst = {1, 1};

/* Each character is separated by last two zeros. The bits are sent lsbit first. */
static const burst_t varicode_table[] = {
	{12, 0x0355}, /* ASCII =   0 101010101100 */
	{12, 0x036d}, /* ASCII =   1 101101101100 */
	{12, 0x02dd}, /* ASCII =   2 101110110100 */
	{12, 0x03bb}, /* ASCII =   3 110111011100 */
	{12, 0x035d}, /* ASCII =   4 101110101100 */
	{12, 0x03eb}, /* ASCII =   5 110101111100 */
	{12, 0x03dd}, /* ASCII =   6 101110111100 */
	{12, 0x02fd}, /* ASCII =   7 101111110100 */
	{12, 0x03fd}, /* ASCII =   8 101111111100 */
	{10, 0x00f7}, /* ASCII =   9 1110111100 */
	{ 7, 0x0017}, /* ASCII =  10 1110100 */
	{12, 0x03db}, /* ASCII =  11 110110111100 */
	{12, 0x02ed}, /* ASCII =  12 101101110100 */
	{ 7, 0x001f}, /* ASCII =  13 1111100 */
	{12, 0x02bb}, /* ASCII =  14 110111010100 */
	{12, 0x0357}, /* ASCII =  15 111010101100 */
	{12, 0x03bd}, /* ASCII =  16 101111011100 */
	{12, 0x02bd}, /* ASCII =  17 101111010100 */
	{12, 0x02d7}, /* ASCII =  18 111010110100 */
	{12, 0x03d7}, /* ASCII =  19 111010111100 */
	{12, 0x036b}, /* ASCII =  20 110101101100 */
	{12, 0x035b}, /* ASCII =  21 110110101100 */
	{12, 0x02db}, /* ASCII =  22 110110110100 */
	{12, 0x03ab}, /* ASCII =  23 110101011100 */
	{12, 0x037b}, /* ASCII =  24 110111101100 */
	{12, 0x02fb}, /* ASCII =  25 110111110100 */
	{12, 0x03b7}, /* ASCII =  26 111011011100 */
	{12, 0x02ab}, /* ASCII =  27 110101010100 */
	{12, 0x02eb}, /* ASCII =  28 110101110100 */
	{12, 0x0377}, /* ASCII =  29 111011101100 */
	{12, 0x037d}, /* ASCII =  30 101111101100 */
	{12, 0x03fb}, /* ASCII =  31 110111111100 */
	{ 3, 0x0001}, /* ASCII = ' ' 100 */
	{11, 0x01ff}, /* ASCII = '!' 11111111100 */
	{11, 0x01f5}, /* ASCII = '"' 10101111100 */
	{11, 0x015f}, /* ASCII = '#' 11111010100 */
	{11, 0x01b7}, /* ASCII = '$' 11101101100 */
	{12, 0x02ad}, /* ASCII = '%' 101101010100 */
	{12, 0x0375}, /* ASCII = '&' 101011101100 */
	{11, 0x01fd}, /* ASCII = ''' 10111111100 */
	{10, 0x00df}, /* ASCII = '(' 1111101100 */
	{10, 0x00ef}, /* ASCII = ')' 1111011100 */
	{11, 0x01ed}, /* ASCII = '*' 10110111100 */
	{11, 0x01f7}, /* ASCII = '+' 11101111100 */
	{ 9, 0x0057}, /* ASCII = ',' 111010100 */
	{ 8, 0x002b}, /* ASCII = '-' 11010100 */
	{ 9, 0x0075}, /* ASCII = '.' 101011100 */
	{11, 0x01eb}, /* ASCII = '/' 11010111100 */
	{10, 0x00ed}, /* ASCII = '0' 1011011100 */
	{10, 0x00bd}, /* ASCII = '1' 1011110100 */
	{10, 0x00b7}, /* ASCII = '2' 1110110100 */
	{10, 0x00ff}, /* ASCII = '3' 1111111100 */
	{11, 0x01dd}, /* ASCII = '4' 10111011100 */
	{11, 0x01b5}, /* ASCII = '5' 10101101100 */
	{11, 0x01ad}, /* ASCII = '6' 10110101100 */
	{11, 0x016b}, /* ASCII = '7' 11010110100 */
	{11, 0x01ab}, /* ASCII = '8' 11010101100 */
	{11, 0x01db}, /* ASCII = '9' 11011011100 */
	{10, 0x00af}, /* ASCII = ':' 1111010100 */
	{11, 0x017b}, /* ASCII = ';' 11011110100 */
	{11, 0x016f}, /* ASCII = '<' 11110110100 */
	{ 9, 0x0055}, /* ASCII = '=' 101010100 */
	{11, 0x01d7}, /* ASCII = '>' 11101011100 */
	{12, 0x03d5}, /* ASCII = '?' 101010111100 */
	{12, 0x02f5}, /* ASCII = '@' 101011110100 */
	{ 9, 0x005f}, /* ASCII = 'A' 111110100 */
	{10, 0x00d7}, /* ASCII = 'B' 1110101100 */
	{10, 0x00b5}, /* ASCII = 'C' 1010110100 */
	{10, 0x00ad}, /* ASCII = 'D' 1011010100 */
	{ 9, 0x0077}, /* ASCII = 'E' 111011100 */
	{10, 0x00db}, /* ASCII = 'F' 1101101100 */
	{10, 0x00bf}, /* ASCII = 'G' 1111110100 */
	{11, 0x0155}, /* ASCII = 'H' 10101010100 */
	{ 9, 0x007f}, /* ASCII = 'I' 111111100 */
	{11, 0x017f}, /* ASCII = 'J' 11111110100 */
	{11, 0x017d}, /* ASCII = 'K' 10111110100 */
	{10, 0x00eb}, /* ASCII = 'L' 1101011100 */
	{10, 0x00dd}, /* ASCII = 'M' 1011101100 */
	{10, 0x00bb}, /* ASCII = 'N' 1101110100 */
	{10, 0x00d5}, /* ASCII = 'O' 1010101100 */
	{10, 0x00ab}, /* ASCII = 'P' 1101010100 */
	{11, 0x0177}, /* ASCII = 'Q' 11101110100 */
	{10, 0x00f5}, /* ASCII = 'R' 1010111100 */
	{ 9, 0x007b}, /* ASCII = 'S' 110111100 */
	{ 9, 0x005b}, /* ASCII = 'T' 110110100 */
	{11, 0x01d5}, /* ASCII = 'U' 10101011100 */
	{11, 0x015b}, /* ASCII = 'V' 11011010100 */
	{11, 0x0175}, /* ASCII = 'W' 10101110100 */
	{11, 0x015d}, /* ASCII = 'X' 10111010100 */
	{11, 0x01bd}, /* ASCII = 'Y' 10111101100 */
	{12, 0x02d5}, /* ASCII = 'Z' 101010110100 */
	{11, 0x01df}, /* ASCII = '[' 11111011100 */
	{11, 0x01ef}, /* ASCII = '\' 11110111100 */
	{11, 0x01bf}, /* ASCII = ']' 11111101100 */
	{12, 0x03f5}, /* ASCII = '^' 101011111100 */
	{11, 0x016d}, /* ASCII = '_' 10110110100 */
	{12, 0x03ed}, /* ASCII = '`' 101101111100 */
	{ 6, 0x000d}, /* ASCII = 'a' 101100 */
	{ 9, 0x007d}, /* ASCII = 'b' 101111100 */
	{ 8, 0x003d}, /* ASCII = 'c' 10111100 */
	{ 8, 0x002d}, /* ASCII = 'd' 10110100 */
	{ 4, 0x0003}, /* ASCII = 'e' 1100 */
	{ 8, 0x002f}, /* ASCII = 'f' 11110100 */
	{ 9, 0x006d}, /* ASCII = 'g' 101101100 */
	{ 8, 0x0035}, /* ASCII = 'h' 10101100 */
	{ 6, 0x000b}, /* ASCII = 'i' 110100 */
	{11, 0x01af}, /* ASCII = 'j' 11110101100 */
	{10, 0x00fd}, /* ASCII = 'k' 1011111100 */
	{ 7, 0x001b}, /* ASCII = 'l' 1101100 */
	{ 8, 0x0037}, /* ASCII = 'm' 11101100 */
	{ 6, 0x000f}, /* ASCII = 'n' 111100 */
	{ 5, 0x0007}, /* ASCII = 'o' 11100 */
	{ 8, 0x003f}, /* ASCII = 'p' 11111100 */
	{11, 0x01fb}, /* ASCII = 'q' 11011111100 */
	{ 7, 0x0015}, /* ASCII = 'r' 1010100 */
	{ 7, 0x001d}, /* ASCII = 's' 1011100 */
	{ 5, 0x0005}, /* ASCII = 't' 10100 */
	{ 8, 0x003b}, /* ASCII = 'u' 11011100 */
	{ 9, 0x006f}, /* ASCII = 'v' 111101100 */
	{ 9, 0x006b}, /* ASCII = 'w' 110101100 */
	{10, 0x00fb}, /* ASCII = 'x' 1101111100 */
	{ 9, 0x005d}, /* ASCII = 'y' 101110100 */
	{11, 0x0157}, /* ASCII = 'z' 11101010100 */
	{12, 0x03b5}, /* ASCII = '{' 101011011100 */
	{11, 0x01bb}, /* ASCII = '|' 11011101100 */
	{12, 0x02b5}, /* ASCII = '}' 101011010100 */
	{12, 0x03ad}, /* ASCII = '~' 101101011100 */
	{12, 0x02b7}, /* ASCII = 127 111011010100 */
	{12, 0x02f7}, /* ASCII = 128 111011110100 */
	{12, 0x03f7}, /* ASCII = 129 111011111100 */
	{12, 0x02af}, /* ASCII = 130 111101010100 */
	{12, 0x03af}, /* ASCII = 131 111101011100 */
	{12, 0x036f}, /* ASCII = 132 111101101100 */
	{12, 0x02ef}, /* ASCII = 133 111101110100 */
	{12, 0x03ef}, /* ASCII = 134 111101111100 */
	{12, 0x035f}, /* ASCII = 135 111110101100 */
	{12, 0x02df}, /* ASCII = 136 111110110100 */
	{12, 0x03df}, /* ASCII = 137 111110111100 */
	{12, 0x02bf}, /* ASCII = 138 111111010100 */
	{12, 0x03bf}, /* ASCII = 139 111111011100 */
	{12, 0x037f}, /* ASCII = 140 111111101100 */
	{12, 0x02ff}, /* ASCII = 141 111111110100 */
	{12, 0x03ff}, /* ASCII = 142 111111111100 */
	{13, 0x0555}, /* ASCII = 143 1010101010100 */
	{13, 0x0755}, /* ASCII = 144 1010101011100 */
	{13, 0x06d5}, /* ASCII = 145 1010101101100 */
	{13, 0x05d5}, /* ASCII = 146 1010101110100 */
	{13, 0x07d5}, /* ASCII = 147 1010101111100 */
	{13, 0x06b5}, /* ASCII = 148 1010110101100 */
	{13, 0x05b5}, /* ASCII = 149 1010110110100 */
	{13, 0x07b5}, /* ASCII = 150 1010110111100 */
	{13, 0x0575}, /* ASCII = 151 1010111010100 */
	{13, 0x0775}, /* ASCII = 152 1010111011100 */
	{13, 0x06f5}, /* ASCII = 153 1010111101100 */
	{13, 0x05f5}, /* ASCII = 154 1010111110100 */
	{13, 0x07f5}, /* ASCII = 155 1010111111100 */
	{13, 0x06ad}, /* ASCII = 156 1011010101100 */
	{13, 0x05ad}, /* ASCII = 157 1011010110100 */
	{13, 0x07ad}, /* ASCII = 158 1011010111100 */
	{13, 0x056d}, /* ASCII = 159 1011011010100 */
	{13, 0x076d}, /* ASCII = 160 1011011011100 */
	{13, 0x06ed}, /* ASCII = 161 1011011101100 */
	{13, 0x05ed}, /* ASCII = 162 1011011110100 */
	{13, 0x07ed}, /* ASCII = 163 1011011111100 */
	{13, 0x055d}, /* ASCII = 164 1011101010100 */
	{13, 0x075d}, /* ASCII = 165 1011101011100 */
	{13, 0x06dd}, /* ASCII = 166 1011101101100 */
	{13, 0x05dd}, /* ASCII = 167 1011101110100 */
	{13, 0x07dd}, /* ASCII = 168 1011101111100 */
	{13, 0x06bd}, /* ASCII = 169 1011110101100 */
	{13, 0x05bd}, /* ASCII = 170 1011110110100 */
	{13, 0x07bd}, /* ASCII = 171 1011110111100 */
	{13, 0x057d}, /* ASCII = 172 1011111010100 */
	{13, 0x077d}, /* ASCII = 173 1011111011100 */
	{13, 0x06fd}, /* ASCII = 174 1011111101100 */
	{13, 0x05fd}, /* ASCII = 175 1011111110100 */
	{13, 0x07fd}, /* ASCII = 176 1011111111100 */
	{13, 0x06ab}, /* ASCII = 177 1101010101100 */
	{13, 0x05ab}, /* ASCII = 178 1101010110100 */
	{13, 0x07ab}, /* ASCII = 179 1101010111100 */
	{13, 0x056b}, /* ASCII = 180 1101011010100 */
	{13, 0x076b}, /* ASCII = 181 1101011011100 */
	{13, 0x06eb}, /* ASCII = 182 1101011101100 */
	{13, 0x05eb}, /* ASCII = 183 1101011110100 */
	{13, 0x07eb}, /* ASCII = 184 1101011111100 */
	{13, 0x055b}, /* ASCII = 185 1101101010100 */
	{13, 0x075b}, /* ASCII = 186 1101101011100 */
	{13, 0x06db}, /* ASCII = 187 1101101101100 */
	{13, 0x05db}, /* ASCII = 188 1101101110100 */
	{13, 0x07db}, /* ASCII = 189 1101101111100 */
	{13, 0x06bb}, /* ASCII = 190 1101110101100 */
	{13, 0x05bb}, /* ASCII = 191 1101110110100 */
	{13, 0x07bb}, /* ASCII = 192 1101110111100 */
	{13, 0x057b}, /* ASCII = 193 1101111010100 */
	{13, 0x077b}, /* ASCII = 194 1101111011100 */
	{13, 0x06fb}, /* ASCII = 195 1101111101100 */
	{13, 0x05fb}, /* ASCII = 196 1101111110100 */
	{13, 0x07fb}, /* ASCII = 197 1101111111100 */
	{13, 0x0557}, /* ASCII = 198 1110101010100 */
	{13, 0x0757}, /* ASCII = 199 1110101011100 */
	{13, 0x06d7}, /* ASCII = 200 1110101101100 */
	{13, 0x05d7}, /* ASCII = 201 1110101110100 */
	{13, 0x07d7}, /* ASCII = 202 1110101111100 */
	{13, 0x06b7}, /* ASCII = 203 1110110101100 */
	{13, 0x05b7}, /* ASCII = 204 1110110110100 */
	{13, 0x07b7}, /* ASCII = 205 1110110111100 */
	{13, 0x0577}, /* ASCII = 206 1110111010100 */
	{13, 0x0777}, /* ASCII = 207 1110111011100 */
	{13, 0x06f7}, /* ASCII = 208 1110111101100 */
	{13, 0x05f7}, /* ASCII = 209 1110111110100 */
	{13, 0x07f7}, /* ASCII = 210 1110111111100 */
	{13, 0x06af}, /* ASCII = 211 1111010101100 */
	{13, 0x05af}, /* ASCII = 212 1111010110100 */
	{13, 0x07af}, /* ASCII = 213 1111010111100 */
	{13, 0x056f}, /* ASCII = 214 1111011010100 */
	{13, 0x076f}, /* ASCII = 215 1111011011100 */
	{13, 0x06ef}, /* ASCII = 216 1111011101100 */
	{13, 0x05ef}, /* ASCII = 217 1111011110100 */
	{13, 0x07ef}, /* ASCII = 218 1111011111100 */
	{13, 0x055f}, /* ASCII = 219 1111101010100 */
	{13, 0x075f}, /* ASCII = 220 1111101011100 */
	{13, 0x06df}, /* ASCII = 221 1111101101100 */
	{13, 0x05df}, /* ASCII = 222 1111101110100 */
	{13, 0x07df}, /* ASCII = 223 1111101111100 */
	{13, 0x06bf}, /* ASCII = 224 1111110101100 */
	{13, 0x05bf}, /* ASCII = 225 1111110110100 */
	{13, 0x07bf}, /* ASCII = 226 1111110111100 */
	{13, 0x057f}, /* ASCII = 227 1111111010100 */
	{13, 0x077f}, /* ASCII = 228 1111111011100 */
	{13, 0x06ff}, /* ASCII = 229 1111111101100 */
	{13, 0x05ff}, /* ASCII = 230 1111111110100 */
	{13, 0x07ff}, /* ASCII = 231 1111111111100 */
	{14, 0x0d55}, /* ASCII = 232 10101010101100 */
	{14, 0x0b55}, /* ASCII = 233 10101010110100 */
	{14, 0x0f55}, /* ASCII = 234 10101010111100 */
	{14, 0x0ad5}, /* ASCII = 235 10101011010100 */
	{14, 0x0ed5}, /* ASCII = 236 10101011011100 */
	{14, 0x0dd5}, /* ASCII = 237 10101011101100 */
	{14, 0x0bd5}, /* ASCII = 238 10101011110100 */
	{14, 0x0fd5}, /* ASCII = 239 10101011111100 */
	{14, 0x0ab5}, /* ASCII = 240 10101101010100 */
	{14, 0x0eb5}, /* ASCII = 241 10101101011100 */
	{14, 0x0db5}, /* ASCII = 242 10101101101100 */
	{14, 0x0bb5}, /* ASCII = 243 10101101110100 */
	{14, 0x0fb5}, /* ASCII = 244 10101101111100 */
	{14, 0x0d75}, /* ASCII = 245 10101110101100 */
	{14, 0x0b75}, /* ASCII = 246 10101110110100 */
	{14, 0x0f75}, /* ASCII = 247 10101110111100 */
	{14, 0x0af5}, /* ASCII = 248 10101111010100 */
	{14, 0x0ef5}, /* ASCII = 249 10101111011100 */
	{14, 0x0df5}, /* ASCII = 250 10101111101100 */
	{14, 0x0bf5}, /* ASCII = 251 10101111110100 */
	{14, 0x0ff5}, /* ASCII = 252 10101111111100 */
	{14, 0x0aad}, /* ASCII = 253 10110101010100 */
	{14, 0x0ead}, /* ASCII = 254 10110101011100 */
	{14, 0x0dad}, /* ASCII = 255 10110101101100 */
};

typedef struct {
	uint32_t c_div;
	int c_mash;
} clock_cb_t;

clock_cb_t clock_cb = {
	.c_div = 0,
	.c_mash = 0,
};

// Sets a GPIO to either GPIO_MODE_IN(=0) or GPIO_MODE_OUT(=1)
static void gpio_set_mode(uint32_t pin, uint32_t mode) {
	uint32_t fsel = gpio_reg[GPIO_FSEL0 + pin/10];

	fsel &= ~(7 << ((pin % 10) * 3));
	fsel |= mode << ((pin % 10) * 3);
	gpio_reg[GPIO_FSEL0 + pin/10] = fsel;
}
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
int main(int argc, char **argv) {
	pi = atan(1) * 4;

	while (1) {
		int opt;
		int opt_index;

		opt_index = 0;
		opt = getopt_long(argc, argv, "a:pt:", long_options, &opt_index);
		if (opt == -1)
			break;
		switch (opt) {
			case 'a':
				option_amplitude = atof(optarg);
				break;
			case 'd':
				option_div = atoi(optarg);
				break;
			case 'f':
				option_frequency = atof(optarg);
				break;
			case 'h':
				fprintf(stderr,
					"Options:\n"
					"  --amplitude=<n>     Signal amplitude (0 .. 1]\n"
					"  --clock-div=<n>     Fractional divisor for carrier [4096 .. 16773120]\n"
					"                      Note: frequency = 500 MHz / (clock-div / 4096)\n"
					"  --frequency=<f>     Carrier frequency, in MHz [0.125 .. 500]\n"
					"                      Note: this is overridden by clock-div\n"
					"  --help              Show this help\n"
					"  --mash=<n>          Set number of MASH stages [0 .. 3]\n"
					"  --pcm               Use PCM clock instead of PWM clock for signal generation\n"
					"  --rc=<f>            Set signal filter RC value (s)\n"
					"  --timeout=<n>       Number of zeros before switching off. 0 for infinite.\n");
				return 0;
			case 'm':
				option_mash = atoi(optarg);
				break;
			case 'p':
				delay_hw = DELAY_VIA_PCM;
				break;
			case 'r':
				option_rc = atof(optarg);
				break;
			case 't':
				option_timeout = atoi(optarg);
				break;
			default:
				fatal("psk31: invalid options\n");
		}
	}

	printf("Using hardware:       %s\n", delay_hw == DELAY_VIA_PWM ? "PWM" : "PCM");
	printf("RC:                   %fs\n", option_rc);
	printf("Amplitude:            %f\n", option_amplitude);
	printf("Timeout:              %d\n", option_timeout);
	printf("Symbol time:          %dus\n", BS_US);
	printf("Buffer time:          %dus\n", TS_COUNT * TS_US);
	printf("Clock div:            %d\n", option_div);
	printf("Mash:                 %d\n", option_mash);
	printf("Frequency:            %f\n", option_frequency);

	setup_sighandlers();

	dma_reg = map_peripheral(DMA_BASE, DMA_LEN);
	pwm_reg = map_peripheral(PWM_BASE, PWM_LEN);
	pcm_reg = map_peripheral(PCM_BASE, PCM_LEN);
	clk_reg = map_peripheral(CLK_BASE, CLK_LEN);
	gpio_reg = map_peripheral(GPIO_BASE, GPIO_LEN);

	/* TODO: retrieve PAGE_SIZE from system */
	virtbase = mmap(NULL, NUM_PAGES * PAGE_SIZE, PROT_READ|PROT_WRITE,
	        MAP_SHARED|MAP_ANONYMOUS|MAP_NORESERVE|MAP_LOCKED,
	        -1, 0);
	if (virtbase == MAP_FAILED)
		fatal("rpio-pwm: Failed to mmap physical pages: %m\n");
	if ((unsigned long)virtbase & (PAGE_SIZE-1))
		fatal("rpio-pwm: Virtual address is not page aligned\n");

	make_pagemap();
	make_physinfo();

	gpio_set(GPIO_POS_NUM, 1);
	gpio_set(GPIO_NEG_NUM, 0);
	gpio_set_mode(GPIO_POS_NUM, GPIO_MODE_OUT);
	gpio_set_mode(GPIO_NEG_NUM, GPIO_MODE_OUT);

	clock_start();

	init_ctrl_data();
	printf("Max. error:           %fmV\n", level_error_max * 3300);
	init_hardware();

	devfiles_unlink();
	devfiles_create();

	if (daemon(0,1) < 0)
		fatal("rpio-pwm: Failed to daemonize process: %m\n");

	go_go_go();

	term_hardware();
	clock_stop();
	devfiles_unlink();

	return 0;
}

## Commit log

2017-11-22 Adding docks and details in diagram
    [vhf_uhf_IQ_Modulator.sch]
2017-11-27 added rf switch
    [vhf_uhf_IQ_Modulator.sch]
2017-11-27 added i and q ref voltage
    [vhf_uhf_IQ_Modulator.sch]
2017-11-27 added power and usb
    [vhf_uhf_IQ_Modulator.sch]
2017-11-30 added dokuments
    [vhf_uhf_IQ_Modulator.sch]
2017-12-02 added new PA 30dbm
    [_saved_vhf_uhf_IQ_Modulator.sch]
2017-12-02 added dokumets
    [_saved_vhf_uhf_IQ_Modulator.sch]
2018-02-12 Added real time clock
    [_saved_vhf_uhf_IQ_Modulator.sch, vhf_uhf_IQ_Modulator.sch]
2018-02-12 added a2d dock
    [_saved_vhf_uhf_IQ_Modulator.sch]
2018-03-19 new simple diagram
    [vhf_uhf_IQ_Modulator_simple.sch]
2018-04-03 adding power amp details
2018-06-01 2m filter and rf switch
    [vhf_uhf_IQ_Modulator.sch, vhf_uhf_IQ_Modulator_simple.sch]
2018-06-02 2m filter
    [vhf_uhf_IQ_Modulator.sch]
2018-06-02 finilising Digarm
    [vhf_uhf_IQ_Modulator.sch]
2018-06-03 Done Anotation
    [vhf_uhf_IQ_Modulator.sch]
2018-06-03 Allocated Footprints
    [vhf_uhf_IQ_Modulator.sch]
2018-06-03 Created Bom and pcbedge
    [vhf_uhf_IQ_Modulator.kicad_pcb]
2018-06-04 redused diagram to fit on pcb
    [vhf_uhf_IQ_Modulator_V2.sch]
2018-06-04 Trying to fic U3 Footprint
    [vhf_uhf_IQ_Modulator_V2.kicad_pcb, vhf_uhf_IQ_Modulator_V2.sch]
2018-06-05 Fixed all Footprints
    [_saved_vhf_uhf_IQ_Modulator_V2.sch]
2018-06-05 Added printable Diagram
    [_saved_vhf_uhf_IQ_Modulator_V2.sch, vhf_uhf_IQ_Modulator_V2.sch]
2018-06-06 added Bom file
    [vhf_uhf_IQ_Modulator_V2.csv]
2018-06-06 Adding PCB image
2018-06-06 Placing components
    [vhf_uhf_IQ_Modulator_V2.kicad_pcb]
2018-06-07 updated Parts list
    [vhf_uhf_IQ_Modulator_V2.csv]
2018-06-07 Placed all components
    [vhf_uhf_IQ_Modulator_V2.kicad_pcb]
2018-06-07 add 3d view
    [vhf_uhf_IQ_Modulator_V2.kicad_pcb]
2018-06-07 PCB placement
2018-06-07 add pcb detail
2018-06-07 Plasing labels
    [vhf_uhf_IQ_Modulator_V2.kicad_pcb]
2018-06-08 Adding diagram
    [vhf_uhf_IQ_Modulator_V2_Digi_Key_V1.csv]
2018-06-09 More rooting
    [vhf_uhf_IQ_Modulator_V2.kicad_pcb]
2018-06-10 23 tracks left
    [vhf_uhf_IQ_Modulator_V2.kicad_pcb]
2018-06-10 19 tracks left
    [vhf_uhf_IQ_Modulator_V2.kicad_pcb]
2018-06-11 add ver3 board
    [_saved_vhf_uhf_IQ_Modulator_V2.sch, vhf_uhf_IQ_Modulator_V3.dsn, vhf_uhf_IQ_Modulator_V3.kicad_pcb]
2018-06-11 Found library error
    [vhf_uhf_IQ_Modulator_V2.sch]
2018-06-11 fix lib and added Resistor
    [vhf_uhf_IQ_Modulator_V3.kicad_pcb]
2018-06-12 fix resistor
    [vhf_uhf_IQ_Modulator_V3.kicad_pcb]
2018-07-05 ver3 Board plased
    [vhf_uhf_IQ_Modulator_V3.kicad_pcb]
2018-07-05 Board now compleat with Groundplane
    [vhf_uhf_IQ_Modulator_V3.kicad_pcb]
2018-07-06 added gerber files
    [vhf_uhf_IQ_Modulator_V3-B.Cu.gbl, vhf_uhf_IQ_Modulator_V3-B.Mask.gbs, vhf_uhf_IQ_Modulator_V3-B.SilkS.gbo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]
2018-08-01 beggining of V4 board
    [_saved_vhf_uhf_IQ_Modulator_V4.sch, vhf_uhf_IQ_Modulator_V4.kicad_pcb, vhf_uhf_IQ_Modulator_V4.sch]
2018-08-01 V4 Board Compleat with Gerber
    [_saved_vhf_uhf_IQ_Modulator_V4.sch, vhf_uhf_IQ_Modulator_V4.csv, vhf_uhf_IQ_Modulator_V4.kicad_pcb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]

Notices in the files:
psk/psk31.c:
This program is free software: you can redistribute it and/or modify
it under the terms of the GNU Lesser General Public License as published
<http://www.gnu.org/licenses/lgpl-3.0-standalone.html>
